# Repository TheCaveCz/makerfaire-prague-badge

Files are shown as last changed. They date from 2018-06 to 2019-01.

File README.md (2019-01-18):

# makerfaire-prague-badge

V tomto repozitáři najdete všechy zdrojové kódy k hardwarovému badge z MakerFaire Prague 2018.

Repozitář má několik částí:

* [Arduino IDE projekt](badge)
* [Schéma pro EAGLE](eagle)
* [Hromadný upload firmware přes USBasp](upload)
* [Programování krok za krokem](programming) - podrobná příručka, jak badge přeprogramovat pomocí Arduino IDE

*Jsme hodně zvědaví, co se vám všechno s badgem podaří vymyslet. Nenechávejte si vaše prográmky jenom pro sebe, klidně je pošlete na info@thecave.cz, rádi je tu zveřejníme!*

## Jak badge vypadá

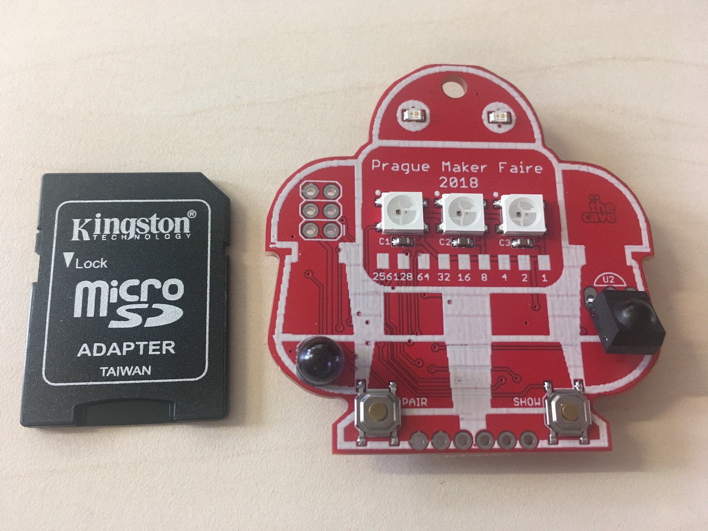
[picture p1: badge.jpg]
The Device


## Poděkování

Výrobu badgů sponzorovalo [Seeed Studio](https://www.seeedstudio.com).

Badges were sponsored by [Seeed Studio](https://www.seeedstudio.com).

Seeed Studio

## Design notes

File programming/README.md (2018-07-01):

# Programování krok za krokem

## Potřebný hardware

Badge je možné programovat přes konektor pro sériovou linku nebo ISP konektor. Každý způsob vyžaduje jiný hardware, jednodušší varianta je programování přes sériovou linku. U té můžete zároveň kontrolovat, co badge přesně dělá, takže budu popisovat jenom tu.

### Sériová linka

Budete potřebovat převodník USB-Serial, propojovací vodiče a USB kabel. Vše se dá pořídit v [GM electro](https://gme.cz) popř. objednat na [Arduino-Shop.cz](https://arduino-shop.cz). Pozor, *převodník musí mít vyvedený pin `DTR`/`RESET`*, bez něj bude programování velmi komplikované.

Nákupní seznam: 

* [Převodník USB-UART, RESET pin](https://www.gme.cz/prevodnik-usb-uart-reset-pin-product-38325) nebo [FTDI převodník s mini USB](https://www.gme.cz/ftdi-prevodnik-s-mini-usb-a-spi)
* [Propojovací vodiče](https://www.gme.cz/propojovaci-vodice-zasuvka-zasuvka-40-kusu) pokud je nemáte k převodníku
* [Oboustranný kolík 2.54mm](https://www.gme.cz/oboustranny-kolik-zl201-06g) abyste mohli propojit badge s vodiči

Badge má ze spodní strany u propojovacího konektoru názvy pinů. Propojte piny se stejnými nebo podobnými názvy.

| Badge | Převodník |
| --- | --- |
| `DTR` | `DTR` |
| `TXD` | `TX` nebo `TXD` |
| `RXI` | `RX` nebo `RXI` nebo `RXD` |
| `VCC` | `VCC` nebo `3V3` |
| `CTS` | `CTS` popř. nemusí být připojeno |
| `GND` | `GND` |

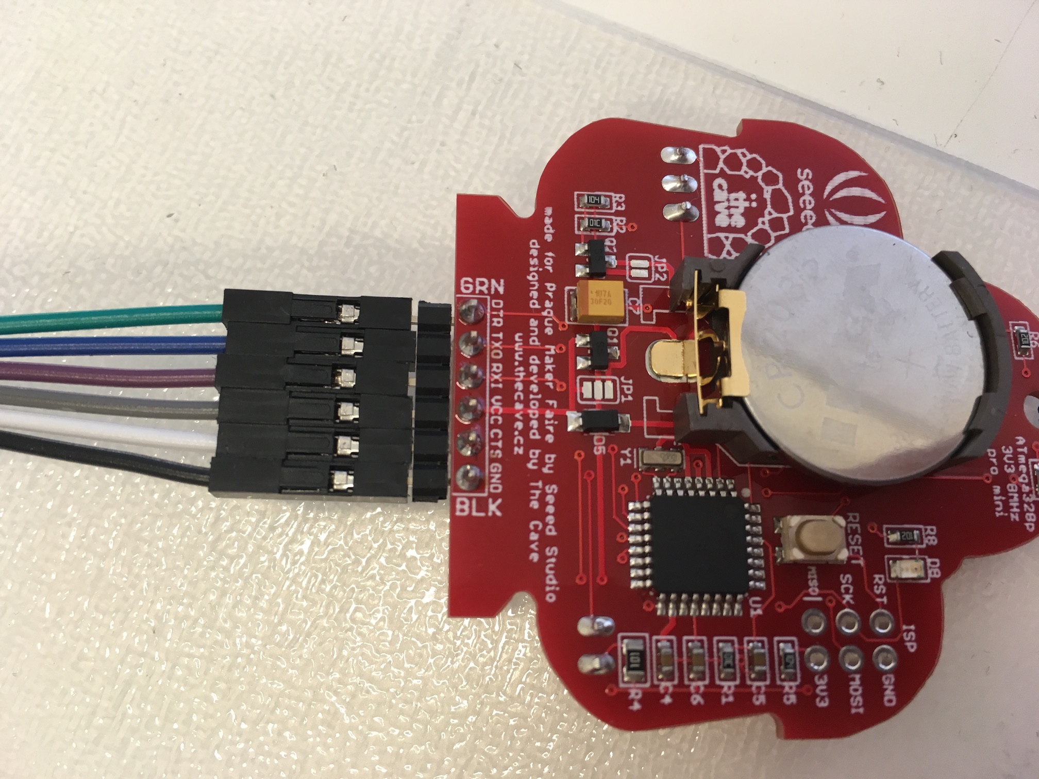
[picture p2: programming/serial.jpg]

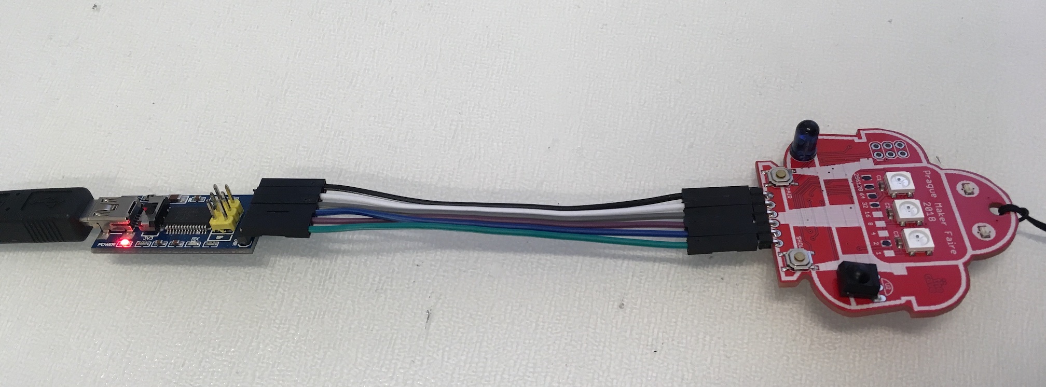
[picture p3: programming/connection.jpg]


## Příprava software

* Nainstalovat ovladače pro USB-Serial převodník
* Stáhnout a nainstalovat Arduino IDE (https://www.arduino.cc/en/Main/Software)
* Stáhnout a rozbalit zdrojové kódy badge (https://github.com/TheCaveCz/makerfaire-prague-badge/archive/master.zip)
* V Arduino IDE nainstalovat knihovnu `TaskScheduler`
  * V hlavním menu `Sketch` > `Include Library` > `Manage Libraries`
  * Do políčka filter your search napsat `TaskScheduler`
  * Klepnout na tlačítko `Install`

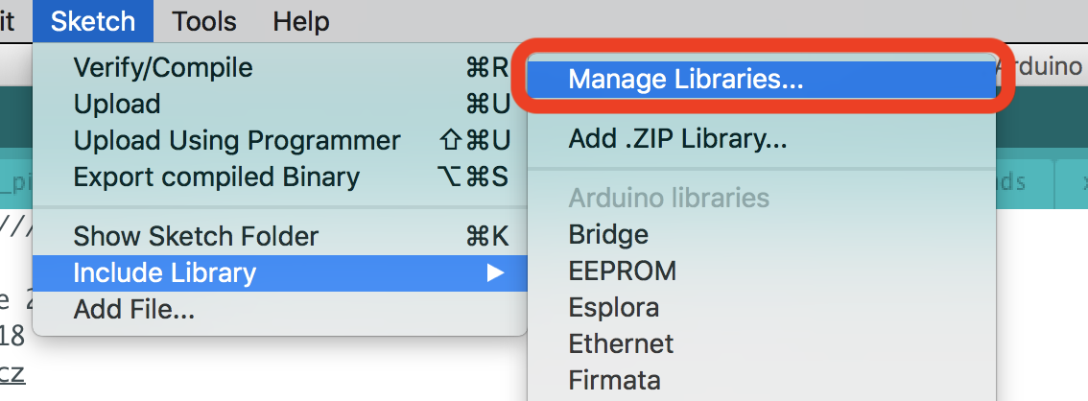
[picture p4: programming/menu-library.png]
Hlavni menu

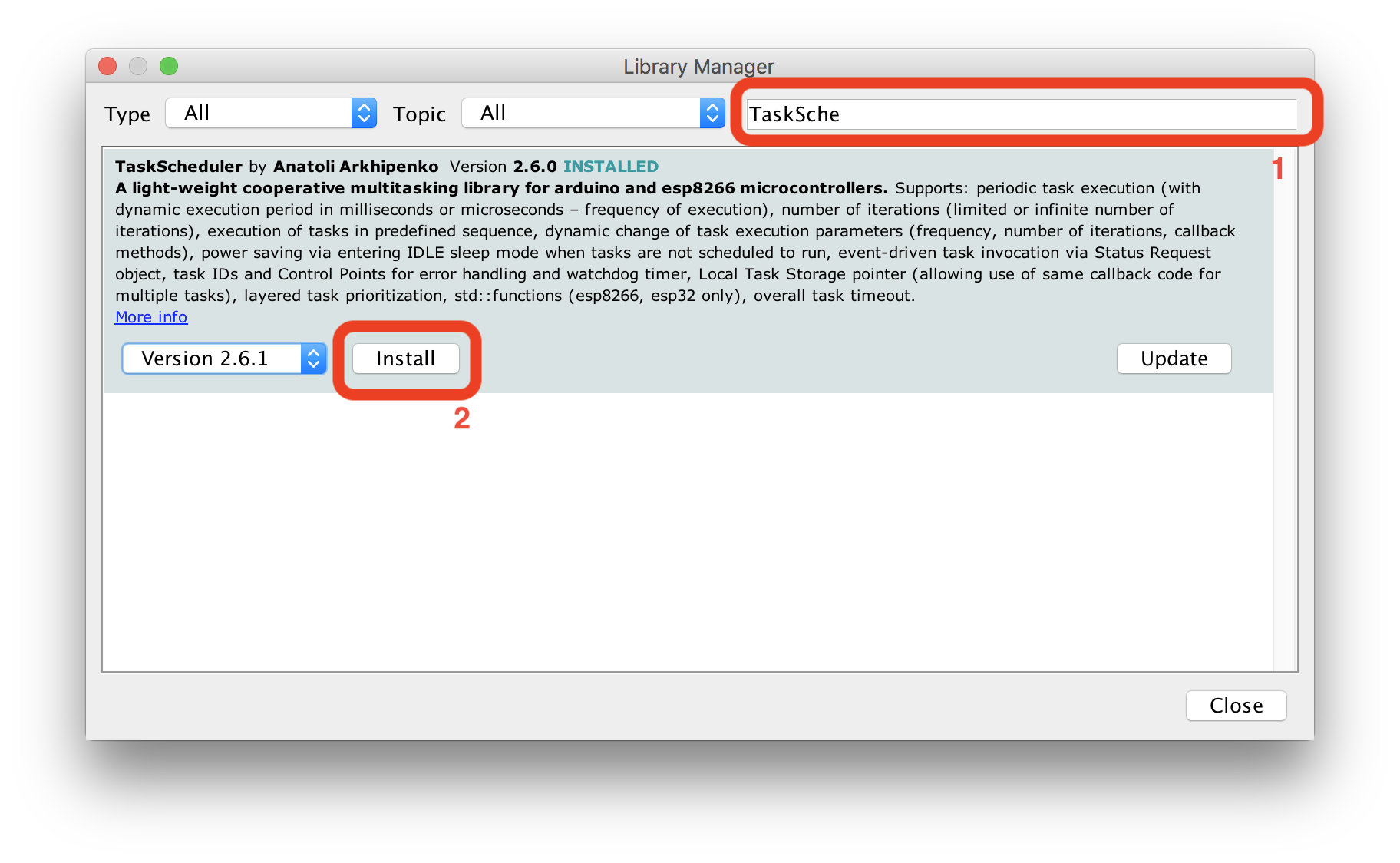
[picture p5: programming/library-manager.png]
Library manager


## Kontrola funkčnosti

* Spusťte Arduino IDE otevřete stažený kód badge (soubor `badge/badge.ino`)
* V menu `Tools` nastavte
  * board na `Arduino Pro or Pro mini`
  * processor na `ATMega328P (3.3V, 8MHz)`
  * port na sériový port vašeho převodníku
* Klepněte na tlačítko Serial Monitor (vpravo nahoře)
* V Serial monitoru nastavte baud rate na `115200 baud`
* Měli byste vidět výpis z badge. Pokud se tak nestane, zkontrolujte, že jste správně vybrali port popř. zkuste prohodit `TXD` a `RXI` signály (některé převodníky je mají zapojené obráceně)

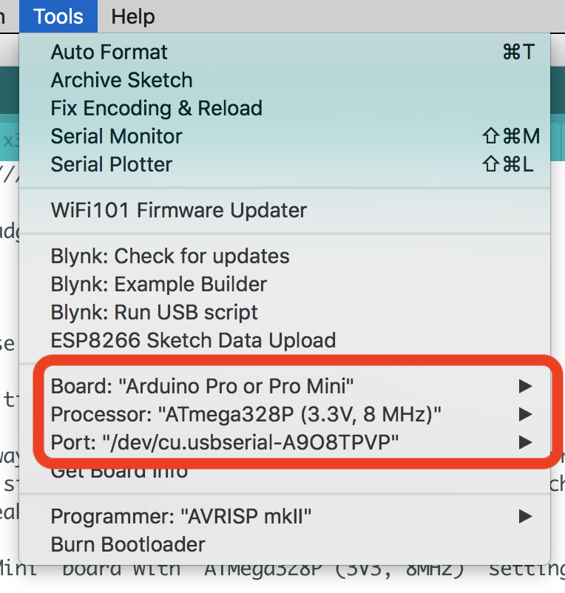
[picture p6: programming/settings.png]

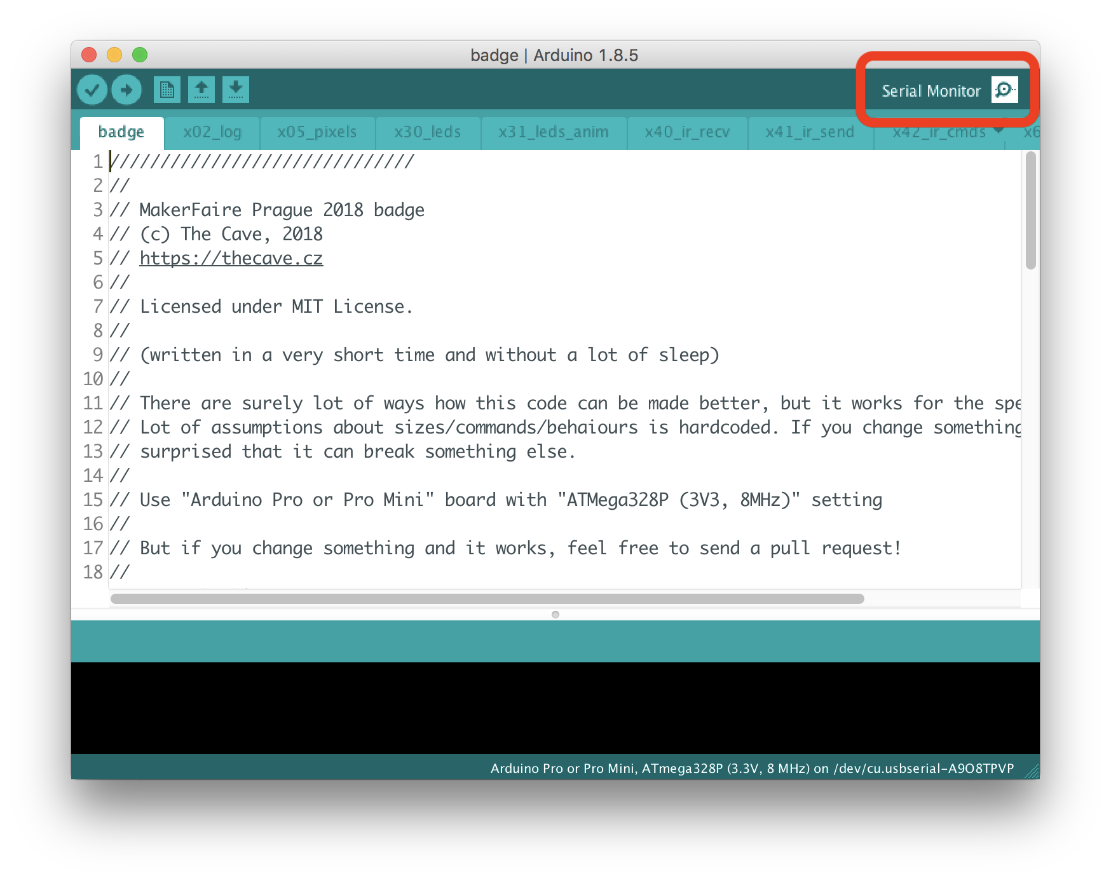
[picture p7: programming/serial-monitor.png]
Serial monitor

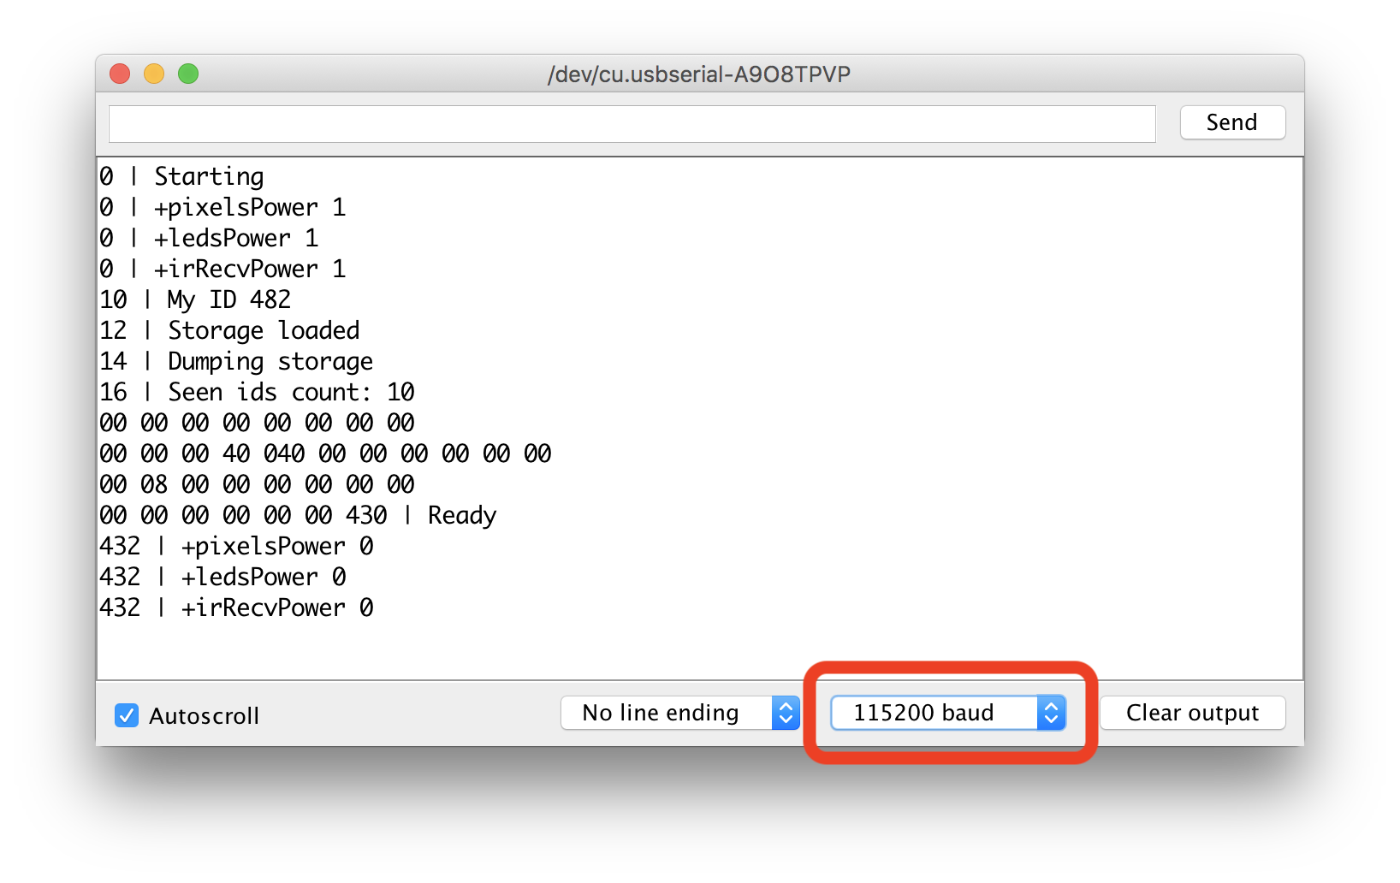
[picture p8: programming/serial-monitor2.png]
Serial monitor


## Programování

Pokud všechno proběhlo v pořádku, můžete začít programovat. Doporučuji vyjít z existujícího kódu a před změnami pořádně prostudovat, co jak funguje. Nový program pošlete do badge stisknutím tlačítka Upload (kulaté tlačítko, druhé vlevo nahoře). Arduino bude chvíli pracovat, pak vám oznámí Done uploading a tím máte hotovo.

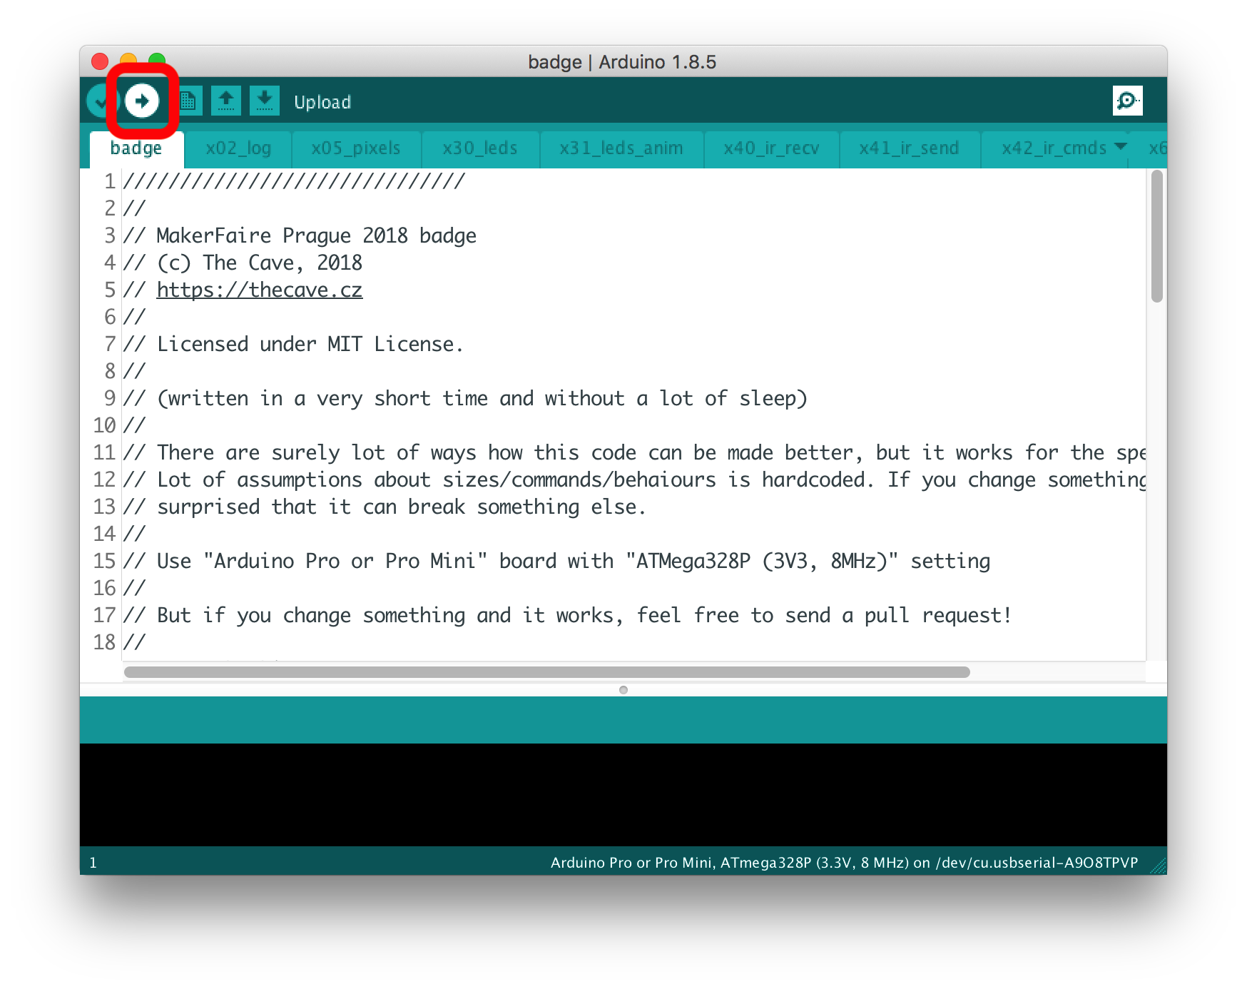
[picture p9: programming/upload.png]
Upload


## Závěrem

Jsme hodně zvědaví, co se vám všechno s badgem podaří vymyslet. Nenechávejte si vaše prográmky jenom pro sebe, klidně je pošlete na info@thecave.cz, rádi je tu zveřejníme! Pokud by vám cokoliv nefungovalo, nebo si nechcete kupovat potřebnou výbavu, zastavte se za námi v [The Cave](https://thecave.cz/navsteva/) a rádi vám pomůžeme!

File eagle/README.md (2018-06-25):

## Schéma

[Plná velikost](https://raw.githubusercontent.com/TheCaveCz/makerfaire-prague-badge/master/eagle/schematic.png)

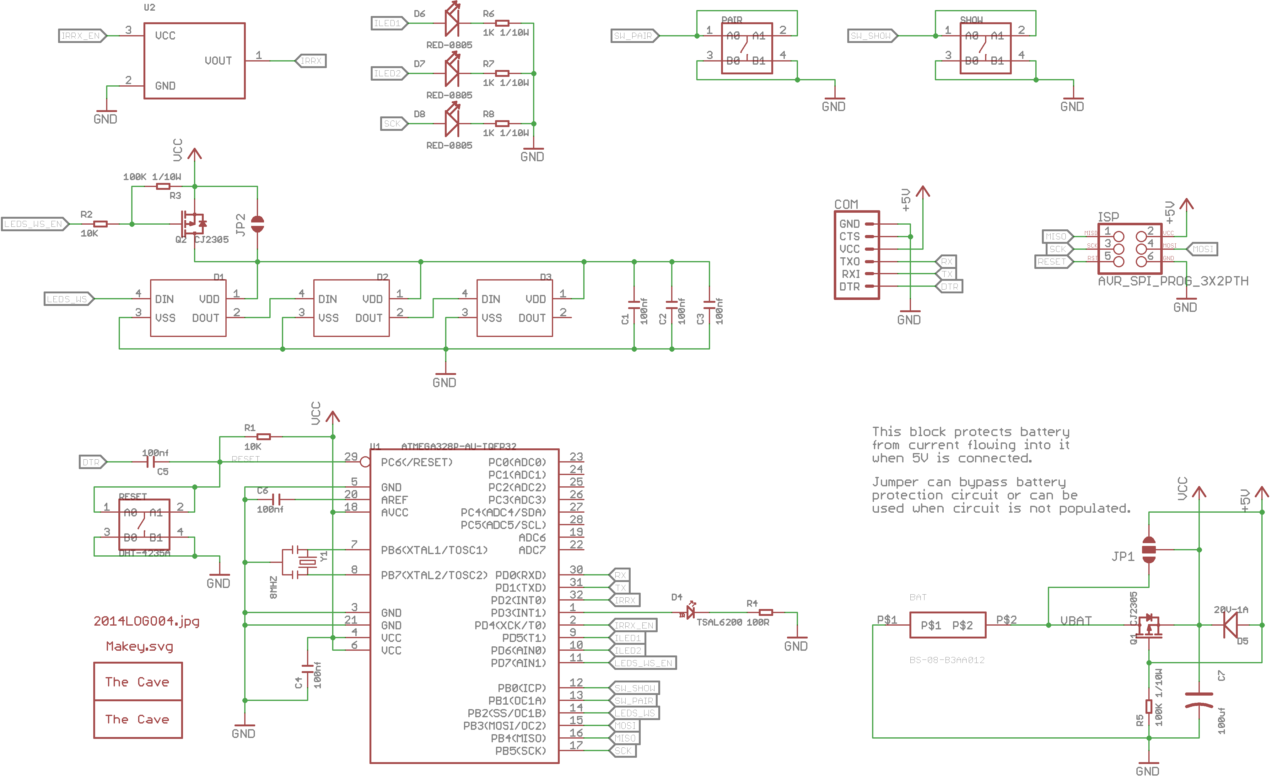
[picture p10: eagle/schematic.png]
schematic


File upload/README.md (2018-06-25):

## Programování 

### Fuses

Fuses jsou nastaveny podle následující tabulky. Jediný rozdíl oproti standardnímu Arduino Pro Mini je `Brown-Out Detect level`.
Je nastavený na hodnotu 1.8V místo 2.7V, protože CR2032 baterka má velký vnitřní odpor a při rychlých změnách barvy se děly brown-out resety. 

[Fuse calculator](http://eleccelerator.com/fusecalc/fusecalc.php?chip=atmega328p&LOW=FF&HIGH=DA&EXTENDED=FE&LOCKBIT=0F)

| fuse | hodnota |
| --- | --- |
| low | 0xFF |
| high | 0xDA |
| extended | 0xFE |
| lock | 0x0F |

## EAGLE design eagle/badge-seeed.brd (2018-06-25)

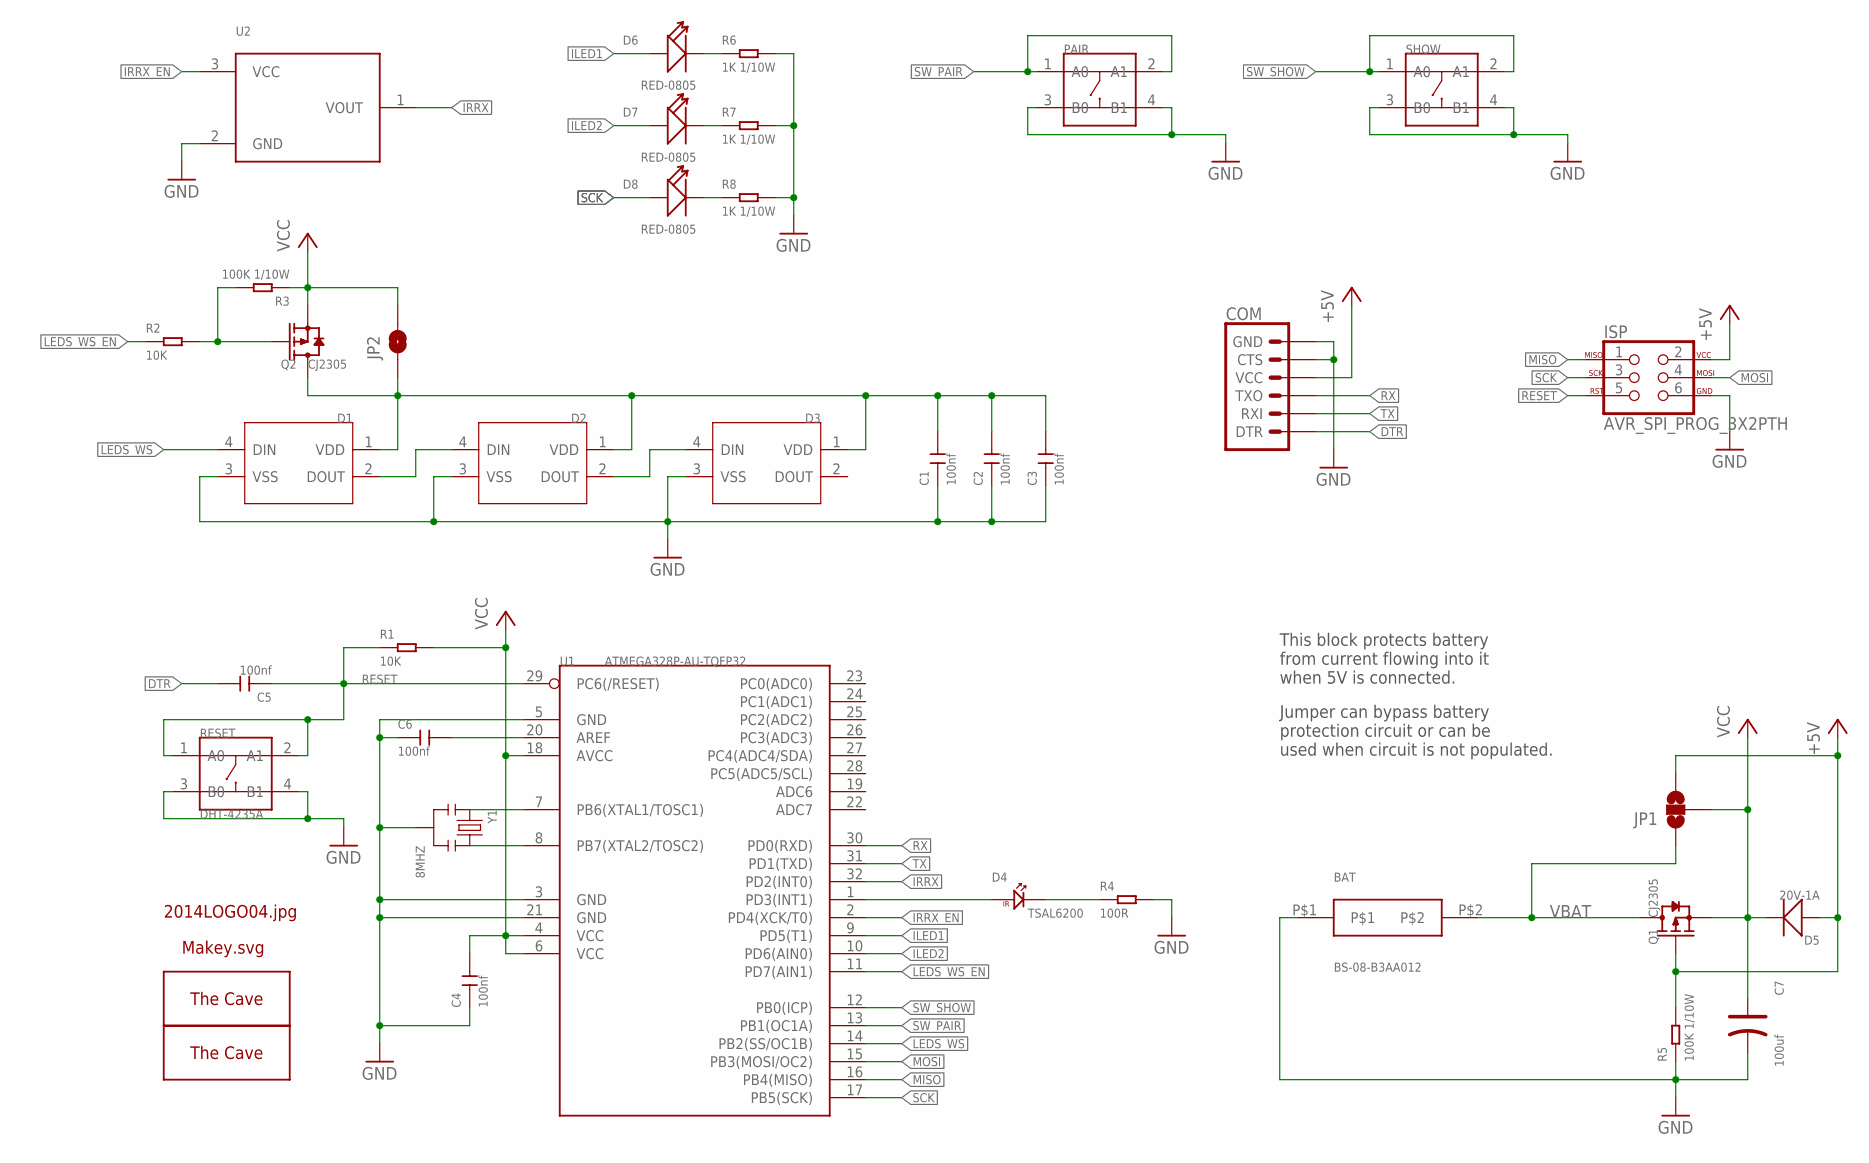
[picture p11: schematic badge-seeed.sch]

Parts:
BAT: BS-08-B3AA012; B3-08-B3AA012
C1, C2, C3, C4, C5, C6: 100nf; C0603
C7: 100uf; AVX-B
COM: 6_PIN_SERIAL_TARGETSILK; 6_PIN_SERIAL_TARGET_SIDE_W_SILK
D1, D2, D3: SMD-RGB-LED-4P'WS2812B'; LED4-SMD-5050
D4: TSAL6200
D5: 20V-1A; SOD-123
D6, D7, D8: RED-0805; LED-0805
ISP: AVR_SPI_PROG_3X2PTH; 2X3
JP1: JUMPER-SMT_3_NO_SILK; SMT-JUMPER_3_NO_SILK
JP2: JUMPER-SMT_2_NO_SILK; SMT-JUMPER_2_NO_SILK
PAIR: SMD-BUTTON(4P-5.2X5.2X1.5MM-SKQGADE010)-SKQGADE010; SW4-SMD-5.2X5.2X1.5MM
Q1, Q2: CJ2305; SOT-23
R1, R2: 10K; R0603
R3, R5: 100K 1/10W; R0603
R4: 100R; R0805
R6, R7, R8: 1K 1/10W; R0603
RESET: DHT-4235A; SW4-SMD-4.2X3.2X2.5MM
SHOW: SMD-BUTTON(4P-5.2X5.2X1.5MM-SKQGADE010)-SKQGADE010; SW4-SMD-5.2X5.2X1.5MM
U1: ATMEGA328P-AU-TQFP32; TQFP32-0.8-7X7MM
U2: TSOP382
U$1: 2014LOGO04#JPG
U$2: MAKEY#SVG
U$3: THECAVE_LOGO_TOP_SMALL; LOGO_TOP_SMALL
U$4: THECAVE_LOGO_COPPER_TEXT; LOGO_COPPER_TEXT
Y1: 8MHZ; X3-SMD-3.6X1.3X0.8MM

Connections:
+5V: COM.P$4 (VCC), D5.+, ISP.2, JP1.3, Q1.1 (G), R5.2
DTR: C5.2, COM.P$1 (DTR)
GND: BAT.P$1, C1.1, C2.1, C3.1, C4.1, C6.1, C7.-, COM.P$5 (CTS), COM.P$6 (GND), D1.3 (VSS), D2.3 (VSS), D3.3 (VSS), ISP.6, PAIR.3 (B0), PAIR.4 (B1), R4.2, R5.1, R6.2, R7.2, R8.2, RESET.3 (B0), RESET.4 (B1), SHOW.3 (B0), SHOW.4 (B1), U1.3 (GND), U1.5 (GND), U1.21 (GND), U2.2 (GND), Y1.2
ILED1: D6.+, U1.9 (PD5(T1))
ILED2: D7.+, U1.10 (PD6(AIN0))
IRRX: U1.32 (PD2(INT0)), U2.1 (VOUT)
IRRX_EN: U1.2 (PD4(XCK/T0)), U2.3 (VCC)
LEDS_WS: D1.4 (DIN), U1.14 (PB2(SS/OC1B))
LEDS_WS_EN: R2.1, U1.11 (PD7(AIN1))
MISO: ISP.1, U1.16 (PB4(MISO))
MOSI: ISP.4, U1.15 (PB3(MOSI/OC2))
unnamed: D1.2 (DOUT), D2.4 (DIN)
unnamed: D2.2 (DOUT), D3.4 (DIN)
unnamed: D7.-, R7.1
unnamed: U1.7 (PB6(XTAL1/TOSC1)), Y1.1
unnamed: U1.8 (PB7(XTAL2/TOSC2)), Y1.3
unnamed: D4.N, R4.1
unnamed: C6.2, U1.20 (AREF)
unnamed: D6.-, R6.1
unnamed: D8.-, R8.1
unnamed: C1.2, C2.2, C3.2, D1.1 (VDD), D2.1 (VDD), D3.1 (VDD), JP2.1, Q2.3 (D)
unnamed: D4.P, U1.1 (PD3(INT1))
unnamed: Q2.1 (G), R2.2, R3.2
RESET: C5.1, ISP.5, R1.1, RESET.1 (A0), RESET.2 (A1), U1.29 (PC6(/RESET))
RX: COM.P$2 (TXO), U1.30 (PD0(RXD))
SCK: D8.+, ISP.3, U1.17 (PB5(SCK))
SW_PAIR: PAIR.1 (A0), PAIR.2 (A1), U1.13 (PB1(OC1A))
SW_SHOW: SHOW.1 (A0), SHOW.2 (A1), U1.12 (PB0(ICP))
TX: COM.P$3 (RXI), U1.31 (PD1(TXD))
VBAT: BAT.P$2, JP1.1, Q1.3 (D)
VCC: C4.2, C7.+, D5.-, JP1.2, JP2.2, Q1.2 (S), Q2.2 (S), R1.2, R3.1, U1.4 (VCC), U1.6 (VCC), U1.18 (AVCC)

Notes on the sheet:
This block protects battery from current flowing into it when 5V is connected.
Jumper can bypass battery protection circuit or can be used when circuit is not populated.

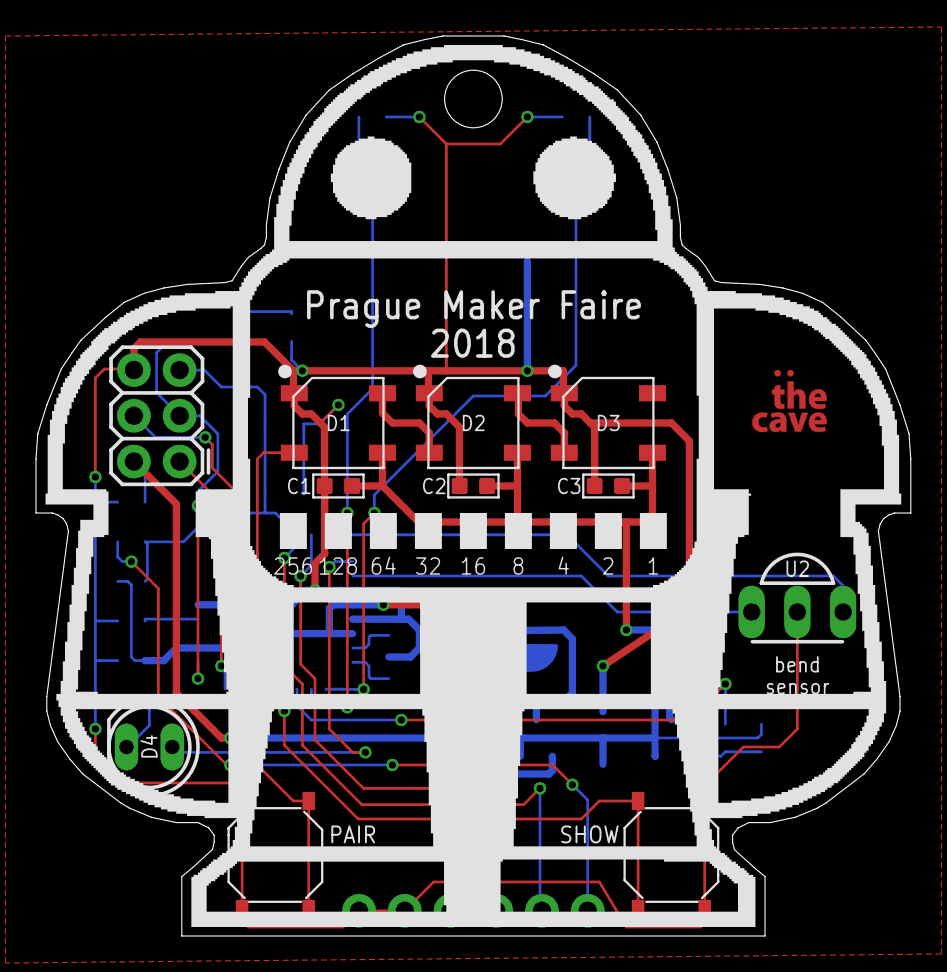
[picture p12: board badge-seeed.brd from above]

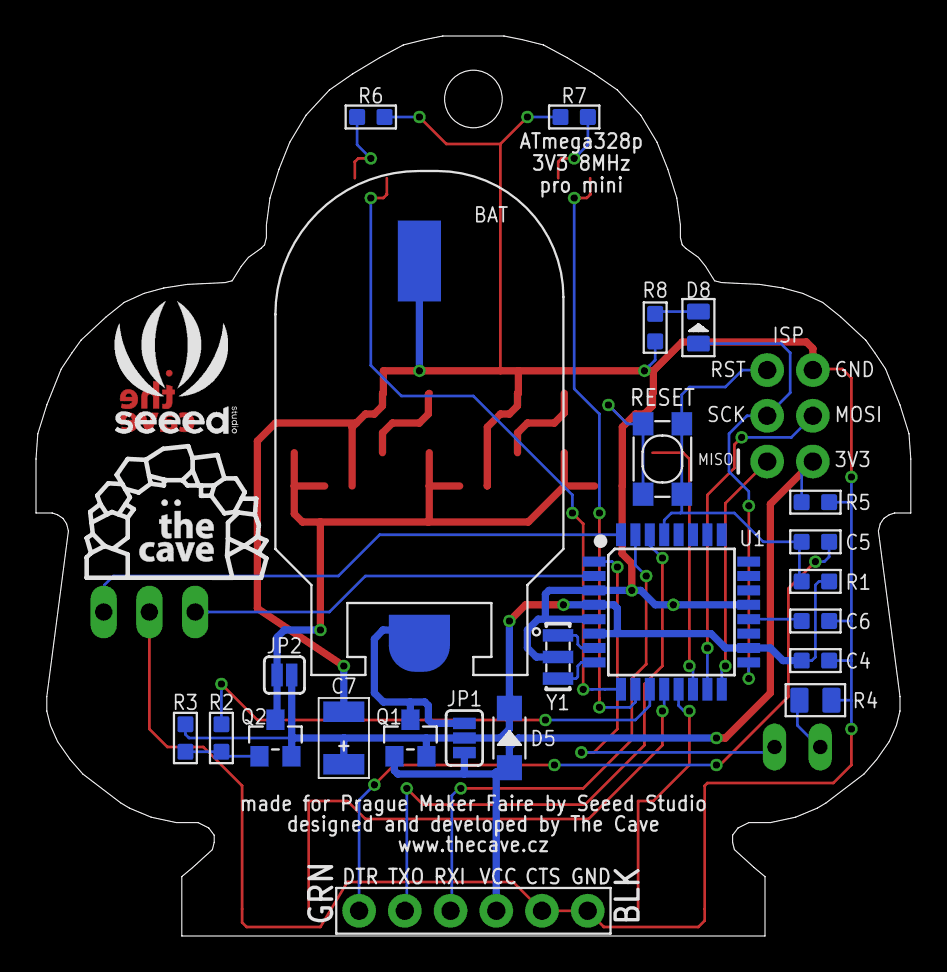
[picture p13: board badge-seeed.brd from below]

Board: 2 copper layers, 48.6 x 50.0 mm, 40 parts (25 on the bottom side), 31 nets.

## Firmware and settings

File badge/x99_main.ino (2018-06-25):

//////////////////////////////
//
// MakerFaire Prague 2018 badge
// (c) The Cave, 2018
// https://thecave.cz
//

//
// Setup and loop
//

void setup() {
#if LOG_ENABLED
  Serial.begin(115200);
#endif
  logInfo("Starting");

  powerSetup();
  pixelsSetup();
  ledsSetup();
  irSendSetup();
  irRecvSetup();
  storageSetup();

  // used for random delays when transmitting presence pulse
  randomSeed(storageMyId);

  // blink eyes at start, useful for programming and detecting resets
  // don't mess with leds anim functions, touch outputs directly
  digitalWrite(PIN_LED1, HIGH);
  digitalWrite(PIN_LED2, HIGH);
  delay(150);
  digitalWrite(PIN_LED1, LOW);
  digitalWrite(PIN_LED2, LOW);
  delay(100);
  digitalWrite(PIN_LED1, HIGH);
  digitalWrite(PIN_LED2, HIGH);
  delay(150);
  digitalWrite(PIN_LED1, LOW);
  digitalWrite(PIN_LED2, LOW);

  // we want to sleep immediately after everything is set up
  logicGoToSleep();
  logInfo("Ready");
}

void loop() {
  // after wakeup from sleep logicCheckSleep function will enable tasks needed
  logicCheckSleep();
  scheduler.execute();
}

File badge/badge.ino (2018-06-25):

//////////////////////////////
//
// MakerFaire Prague 2018 badge
// (c) The Cave, 2018
// https://thecave.cz
//
// Licensed under MIT License.
//
// (written in a very short time and without a lot of sleep)
// 
// There are surely lot of ways how this code can be made better, but it works for the specific case we had.
// Lot of assumptions about sizes/commands/behaiours is hardcoded. If you change something, don't be
// surprised that it can break something else.
//
// Use "Arduino Pro or Pro Mini" board with "ATMega328P (3V3, 8MHz)" setting
//
// But if you change something and it works, feel free to send a pull request!
//
// Happy hacking!
//

#include <EEPROM.h>
#include <TaskScheduler.h>
#include <avr/sleep.h>
#include <avr/power.h>
#include <avr/interrupt.h>

// enable serial line debug info output
#define LOG_ENABLED 1


// Pin Assignments

// PB2 (dip 16) output - data ouput line for WS2818 LEDS
#define PIN_LEDS_WS 10
// PD7 (dip 13) output - gate for P-MOSFET controlling WS2818 VCC line
#define PIN_LEDS_WS_ENABLE 7
// PD4 (dip 6) output - VCC for IR receiver
#define PIN_IRRX_EN 4
// PD2 (dip 4) input - data input line from IR receiver
#define PIN_IRRX 2
// PD3 (dip 5) output - IR led 
#define PIN_IRTX 3
// PD6 (dip 12) output - left eye LED
#define PIN_LED1 6
// PD5 (dip 11) output - right eye LED
#define PIN_LED2 5
// PB5 builtin led - LED on the back of the robot
#define PIN_LED3 13

// both buttons need to be on the same port
// if you change pins you need to change the pin change interrupt regs too!
// PB1 (dip 15) input pullup - PAIR button
#define PIN_SW1 9
// PB0 (dip 14) input pullup - SHOW button
#define PIN_SW2 8


Scheduler scheduler;

// NOTE : you may see function prototypes declarations in the source
// for some reason Arduino IDE fails to generate function prototypes in this source

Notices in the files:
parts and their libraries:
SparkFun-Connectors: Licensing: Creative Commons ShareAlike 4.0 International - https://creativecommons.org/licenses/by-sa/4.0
